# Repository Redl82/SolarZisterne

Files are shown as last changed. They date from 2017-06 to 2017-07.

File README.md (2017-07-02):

# SolarZisterne

Es handelt sich bei diesem Projekt um einen Füllstandsmesser für eine Außen-Zisterne.
Der Füllstandsmesser wir über einen ESP8266 mit dem Netzwerkverbunden und agiert als eigenständiger Web-Server.
Die Stromversorgung wird über Solarzellen gewährleistet.
Das Projekt besitz die folgenden Sensoren:
- Ultraschall Sensor für Füllstand
- Temperatur/Luftfeuchte/Luftdruck Sensor außen
- Temperatur/Luftdruck Sensor innen
- Spannung/Strom Sensor Produktion Solarzellen
- Spannung/Strom Sensor Verbrauch Elektronik

Die Lade Schaltung kann die follgenden Zustände annehmen:
            GPIO2   GPIO1   GPIO0
     Wert   STAT1   STAT2   PG      Status
     7      1       1       1       Input Power Not OK / Shutdown
     6      1       1       0       Input Power OK / No Battery Present
     4      1       0       0       Input Power OK / Charge Complete - Standby
     3      0       1       1       Input Power Not OK / Low Battery Output
     2      0       1       0       Input Power OK / Chargin Batter in Constant Current/Voltage or Preconding Mode
     0      0       0       0       Input Power OK / Temperature Fault / Temperatur Fault

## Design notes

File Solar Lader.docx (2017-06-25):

SM3320

Scheinbar nicht mehr verfügbar

SPV1040

Preiß: 4,99€

Minus:

- geht nur bis 5,5V Eingangsspannung
- Maxspannung nicht über Akkuspannung, wenn doch Akku lade IC verwenden

LT3652

Minus:

- Zieht 2,5mA aus Akku bevor geladen wird

LTM8062

BQ25504

Günstige PCBs

https://www.elecrow.com/5pcs-2-layer-pcb.html

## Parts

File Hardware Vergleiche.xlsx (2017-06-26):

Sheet: Lade ICs
 |  | ebay | aliexpress | conrad | reichelt | farnell
BQ24210 | nix
BQ25504 | 7.98 | ebay | 30 5stück |  |  | 5.99
BQ25570 | 21 | http://www.ebay.de/itm/BQ25570-thermal-solar-energy-harvester-/332071662285
LTC3105/LTC4071 |  | 3.58 | 12 5Stück | 9.13 |  | 5.27
 |  |  | 11
 |  | 11 | 34 10 Stück
LTC3106 |  |  | 17,29 2 stück |  |  | 7.05
LTC3331 |  | 11 |  |  |  | 8.73
MAX17710 |  |  |  |  |  | 15.61
ADP5090 |  | 9 |  |  |  | 5.27

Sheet: I2C Temp Sensoren
Name | Temperatur | Luftfeuchte | Druck | Temp Genauigkeit | Preis | Kommentare
BME280 | X | X | X | +/-1 | 3.75 €
MCP9808 | X |  |  | +/-0,25 | ca. 6 | günstigste nicht E-bay
MPL115A2 | X |  | X | ??? | 9.00 € | Nur ein feste Adresse
BMP280 | X |  | X | +/-1 | 1.00 €
SHT31-D | X | X |  | +/-0,3 | 5.25 €
HDC1008 | X | X |  | +/-0,2 | 3.79 € | nicht direkt
BMP085 | X | X | X | +/-2 |  | Nur ein feste Adresse, überholt

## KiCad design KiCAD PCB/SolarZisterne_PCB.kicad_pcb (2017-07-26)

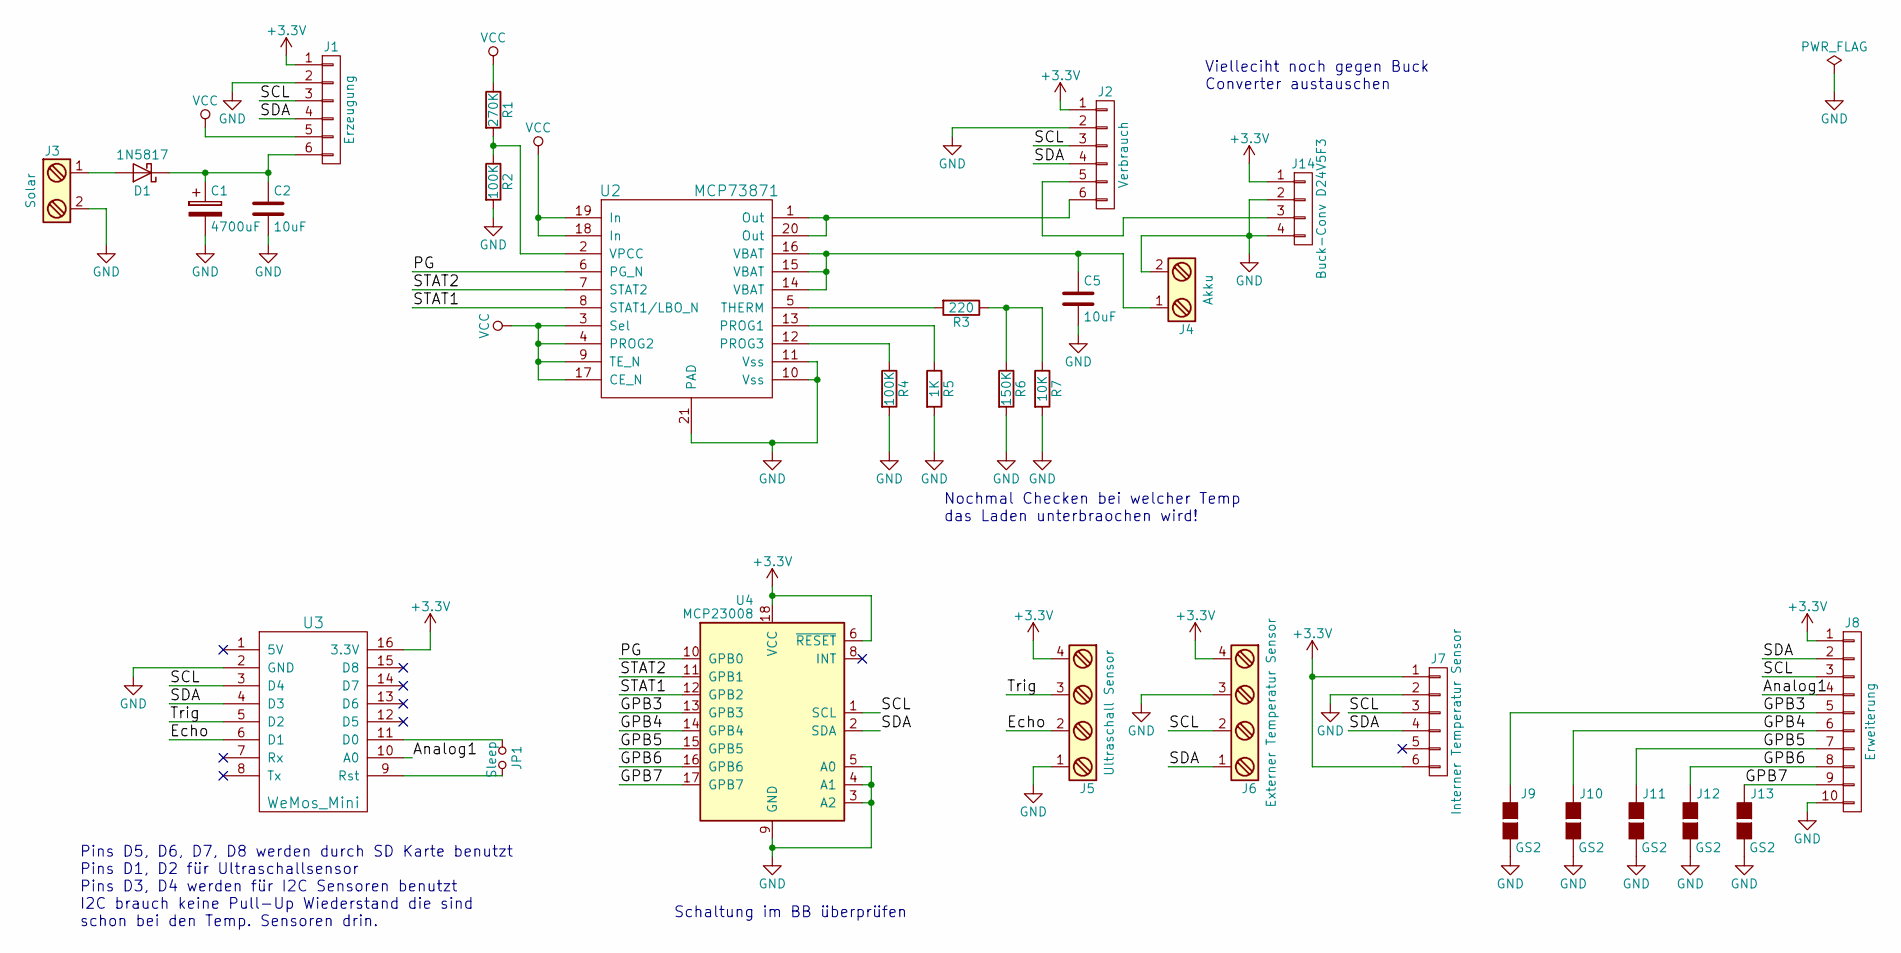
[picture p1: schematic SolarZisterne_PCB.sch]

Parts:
C1: 4700uF; CP_Radial_D16.0mm_P7.50mm
C2, C5: 10uF; C_Disc_D5.0mm_W2.5mm_P2.50mm
D1: 1N5817; D_DO-41_SOD81_P10.16mm_Horizontal
J1: Erzeugung; Pin_Header_Straight_1x06_Pitch2.54mm
J2: Verbrauch; Pin_Header_Straight_1x06_Pitch2.54mm
J3: Solar; TerminalBlock_Pheonix_PT-3.5mm_2pol
J4: Akku; TerminalBlock_Pheonix_PT-3.5mm_2pol
J5: Ultraschall Sensor; TerminalBlock_Pheonix_PT-3.5mm_4pol
J6: Externer Temperatur Sensor; TerminalBlock_Pheonix_PT-3.5mm_4pol
J7: Interner Temperatur Sensor; Pin_Header_Straight_1x06_Pitch2.54mm
J8: Erweiterung; Pin_Header_Straight_1x10_Pitch2.54mm
J9, J10, J11, J12, J13: GS2
J14: Buck-Conv D24V5F3; Pin_Header_Straight_1x04_Pitch2.54mm
JP1: Sleep; Pin_Header_Straight_1x02_Pitch2.54mm
R1: 270K; R_Axial_DIN0207_L6.3mm_D2.5mm_P10.16mm_Horizontal
R2, R4: 100K; R_Axial_DIN0207_L6.3mm_D2.5mm_P10.16mm_Horizontal
R3: 220; R_Axial_DIN0207_L6.3mm_D2.5mm_P10.16mm_Horizontal
R5: 1K; R_Axial_DIN0207_L6.3mm_D2.5mm_P10.16mm_Horizontal
R6: 150K; R_Axial_DIN0207_L6.3mm_D2.5mm_P10.16mm_Horizontal
R7: 10K; R_Axial_DIN0207_L6.3mm_D2.5mm_P10.16mm_Horizontal
U2: MCP73871; QFN-20-1EP_4x4mm_Pitch0.5mm
U3: WeMos_Mini; D1_mini_board
U4: MCP23008; DIP-18_W7.62mm_LongPads

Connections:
+3V3: J1.1, J2.1, J5.4, J6.4, J7.1, J7.6, J8.1, J14.1, U3.16 (3.3V), U4.6 (~RESET), U4.18 (VCC)
/Analog1: J8.4, U3.10 (A0)
/Echo: J5.2, U3.6 (D1)
/GPB3: J8.5, J9.1 (G1), U4.13 (GPB3)
/GPB4: J8.6, J10.1 (G1), U4.14 (GPB4)
/GPB5: J8.7, J11.1 (G1), U4.15 (GPB5)
/GPB6: J8.8, J12.1 (G1), U4.16 (GPB6)
/GPB7: J8.9, J13.1 (G1), U4.17 (GPB7)
/PG: U2.6 (PG_N), U4.10 (GPB0)
/SCL: J1.3, J2.3, J6.2, J7.3, J8.3, U3.3 (D4), U4.1 (SCL)
/SDA: J1.4, J2.4, J6.1, J7.4, J8.2, U3.4 (D3), U4.2 (SDA)
/STAT1: U2.8 (STAT1/LBO_N), U4.12 (GPB2)
/STAT2: U2.7 (STAT2), U4.11 (GPB1)
/Trig: J5.3, U3.5 (D2)
GND: C1.2, C2.2, C5.2, J1.2, J2.2, J3.2, J4.2, J5.1, J6.3, J7.2, J8.10, J9.2 (G2), J10.2 (G2), J11.2 (G2), J12.2 (G2), J13.2 (G2), J14.2, J14.4, R2.2, R4.2, R5.2, R6.2, R7.2, U2.10 (Vss), U2.11 (Vss), U2.21 (PAD), U3.2 (GND), U4.3 (A2), U4.4 (A1), U4.5 (A0), U4.9 (GND)
unnamed: C1.1, C2.1, D1.1 (K), J1.6
unnamed: C5.1, J4.1, U2.14 (VBAT), U2.15 (VBAT), U2.16 (VBAT)
unnamed: D1.2 (A), J3.1
unnamed: J2.6, U2.1 (Out), U2.20 (Out)
unnamed: J2.5, J14.3
unnamed: JP1.1, U3.11 (D0)
unnamed: JP1.2, U3.9 (Rst)
unnamed: R1.2, R2.1, U2.2 (VPCC)
unnamed: R3.1, R6.1, R7.1
unnamed: R3.2, U2.5 (THERM)
unnamed: R4.1, U2.12 (PROG3)
unnamed: R5.1, U2.13 (PROG1)
VCC: J1.5, R1.1, U2.3 (Sel), U2.4 (PROG2), U2.9 (TE_N), U2.17 (CE_N), U2.18 (In), U2.19 (In)

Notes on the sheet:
Pins D5, D6, D7, D8 werden durch SD Karte benutzt Pins D1, D2 für Ultraschallsensor Pins D3, D4 werden für I2C Sensoren benutzt I2C brauch keine Pull-Up Wiederstand die sind schon bei den Temp. Sensoren drin.
Nochmal Checken bei welcher Temp das Laden unterbraochen wird!
Schaltung im BB überprüfen
Vielleciht noch gegen Buck Converter austauschen

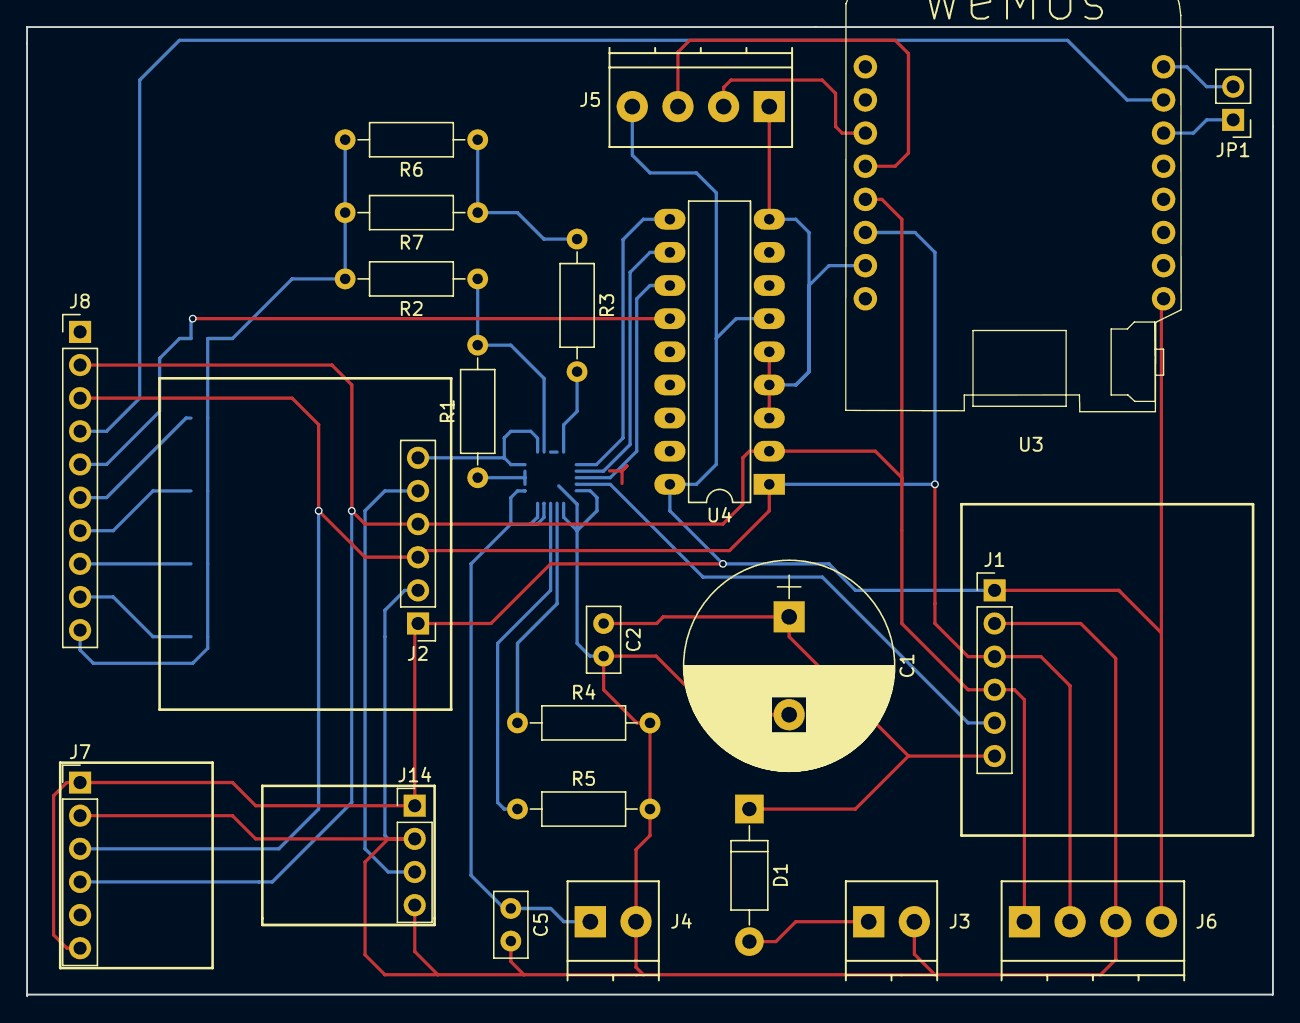
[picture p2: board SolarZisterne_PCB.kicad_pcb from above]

Board: 2 copper layers, 95.5 x 74.3 mm, 29 parts (0 on the bottom side), 28 nets.

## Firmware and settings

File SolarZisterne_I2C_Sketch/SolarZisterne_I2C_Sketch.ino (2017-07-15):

/*---------------------------------------------------
HTTP 1.1 Outdoor Webserver for WeMos Mini
for ESP8266 adapted Arduino IDE

by Daniel 07/2017 - free for anyone
---------------------------------------------------*/

#include <ESP8266WiFi.h>
#include <WiFiUdp.h>
#include <SPI.h>
#include <SD.h>
#include <Wire.h>                        // I2C
#include <Adafruit_INA219.h>             // INA219 Strommessung
#include "Adafruit_MCP23008.h"           // MCP23008
#include <Adafruit_Sensor.h>             // benötigt für Temperatur Senoren
#include <Adafruit_BME280.h>             // BME280 Temperatur Luftdruck Luftfeuchtigkeit Sensor
#include <Adafruit_BMP280.h>             // BMP280 Temperatur Luftdruck Sensor
#include "time_ntp.h"
#include "DHT.h"

// WiFi connection
const char* ssid = "Your SSID";
const char* password = "Your PW";

// ntp timestamp
unsigned long ulSecs2000_timer=0;

// storage for Measurements; keep some mem free; allocate remainder
#define KEEP_MEM_FREE 10240
#define MEAS_SPAN_H 4                   // Dauer bis Speicher, voll in Stunden 744h-->31Tage Messung ca. all 20 Min.
unsigned long ulMeasCount=0;            // values already measured
unsigned long ulNoMeasValues=0;         // size of array
unsigned long ulMeasDelta_ms;           // distance to next meas time
unsigned long ulNextMeas_ms;            // next meas time
unsigned long *pulTime;                 // array for time points of measurements
float *pfTemp,*pfHum,*pfDist;           // array for temperature, humidity and Distance measurements
float pfPres, pfTempIn, pfPresIn;        // Werte Luftdruck außen, Temperatur und Luftdruck innen
float pfSolarSp, pfSolarSt, pfSolarLe;  // Werte für Solar Spannung Strom und Leistung
float pfVerbSp, pfVerbSt, pfVerbLe;    // Werte für Verbraucher Spannung Strom und Leistung
String stStatus;                         // Array für Status 

unsigned long ulReqcount;       // how often has a valid page been requested
unsigned long ulReconncount;    // how often did we connect to WiFi

// Create an instance of the server on Port 80
WiFiServer server(80);

//////////////////////////////
// DHT21 / AMS2301 is at GPIO0
//////////////////////////////
#define DHTPIN D3

//////////////////////////////
// Ultraschall Sensor HC-SR04 Pin definition
//////////////////////////////
#define TRIGGER D4
#define ECHO    D3

// set up variables using the SD utility library functions:
Sd2Card card;
SdVolume volume;
SdFile root;

// change this to match your SD shield or module;
// WeMos Micro SD Shield: D8
const int chipSelect = D8;


//mathematische Definition des Volumens der Zisterne



// needed to avoid link error on ram check
extern "C" 
{
#include "user_interface.h"
}
// Deklariert Digitalport expander MCP23008
Adafruit_MCP23008 mcp;

// Deklariert StromMessensor INA219 
Adafruit_INA219 ina219in;                           //Sensor vor MCP73871
Adafruit_INA219 ina219out(0x41);                    //Sensor nach MCP73871

// Deklariert Temperatur Sensoren BME280 und BMP280
Adafruit_BME280 bme; // I2C
Adafruit_BMP280 bmp; // I2C

/////////////////////
// the setup routine
/////////////////////
void setup() 
{
  // setup globals
  ulReqcount=0; 
  ulReconncount=0;
    
  // start serial
  Serial.begin(9600);
  Serial.println();
  Serial.println("########################################################################################################");
  Serial.println("#Zisternen Wasserstandsanzeige, Temperatur und Feuchtigkeitslogger - D. Redlich 04/2017                #");
  Serial.println("#Basis des Programms kann unter:                                                                       #");
  Serial.println("#https://blog.thesen.eu/wlan-lufttemperatur-und-feuchte-logger-mit-grafischer-darstellung-fuer-esp8266/#");
  Serial.println("#gefunden werden.                                                                                      #");
  Serial.println("########################################################################################################");
  Serial.println();
  
  //Start I2C
  Wire.begin();
  Serial.println("########################################################################################################");
  Serial.println("");
  Serial.println("I2C initialisiert!");
  Serial.println("SCL auf Pin D1 und SCA auf Pin D2");
  //Sucht nach benutzten GPIO Adressen
  byte error, address;
  int nDevices;

  Serial.println("Suche nach Geräten...");
  
  nDevices = 0;
  for(address = 1; address < 127; address++ ) 
  {
    // The i2c_scanner uses the return value of
    // the Write.endTransmisstion to see if
    // a device did acknowledge to the address.
    Wire.beginTransmission(address);
    error = Wire.endTransmission();

    if (error == 0)
    {
      Serial.print("I2C Gerät auf adresse 0x");
      if (address<16) 
        Serial.print("0");
      Serial.print(address,HEX);
      Serial.println("  gefunden !");

      nDevices++;
    }
    else if (error==4) 
    {
      Serial.print("Unknown error at address 0x");
      if (address<16) 
        Serial.print("0");
      Serial.println(address,HEX);
    }    
  }
  if (nDevices == 0)
    Serial.println("No I2C devices found\n");
  else
    Serial.println("Fertsch\n");

  mcp.begin();                // use default address 0x20 oder 0 GPIO Expander 
  
  Serial.println("GPIO Erweiterung auf 0x20 eingerichtet!");
  
  mcp.pinMode(0, INPUT);      // definiert Pin 0 als Input --> PG
  mcp.pinMode(1, INPUT);      // definiert Pin 1 als Input --> STAT2
  mcp.pinMode(2, INPUT);      // definiert Pin 2 als Input --> STAT1
  mcp.pullUp(0, HIGH);        // turn on a 100K pullup internally
  mcp.pullUp(1, HIGH);        // turn on a 100K pullup internally
  mcp.pullUp(2, HIGH);        // turn on a 100K pullup internally

  Serial.println("GPIO0 --> PG");
  Serial.println("GPIO1 --> STAT1");
  Serial.println("GPIO2 --> STAT2");

  Serial.println("Pull-Up Wiederstände wurden eingeschaltet");
  
  Serial.println("");
  Serial.println("########################################################################################################");
  Serial.println("");

  //Einrichten der Stromsensoren
  Serial.println("########################################################################################################");
  Serial.println("");
  ina219in.begin();
  ina219out.begin();
  Serial.println("Sensor zum messen des Solar Eingans Stromes und Spannung wurden auf der Adresse 0X40 eingerichtet");
  Serial.println("Sensor zum messen des Verbrauchten Stromes und Spannung wurden auf der Adresse 0X41 eingerichtet");
  Serial.println("");
  Serial.println("########################################################################################################");
  Serial.println("");

  //Einrichten der Temperatur Sensoren
  Serial.println("########################################################################################################");
  Serial.println("");
  bme.begin();
  bmp.begin();
  if (!bmp.begin()) 
  {  
    Serial.println("BMP280 Sensor konnt auf auf 0X77 gefunden werden");
  }
  else
  {
  Serial.println("Sensor zum messen des internen Temperatur(BMP280) wurden auf der Adresse 0X77 eingerichtet"); 
  }
  if (!bme.begin(0x76)) 
  {  
    Serial.println("BME280 Sensor konnt auf auf 0X76 gefunden werden");
  }
  else
  {
  Serial.println("Sensor zum messen des externen Temperatur (BME280) wurden auf der Adresse 0X76 eingerichtet"); 
  }
  Serial.println("");
  Serial.println("########################################################################################################");
  Serial.println("");
  
  //Definition der Pins für Ultraschall Sensor
  pinMode(TRIGGER, OUTPUT);
  pinMode(ECHO, INPUT);
  Serial.println("########################################################################################################");
  Serial.println("");
  Serial.println("Ultraschall Sensor wurde wie folgt eingerichte:");
  Serial.println("Ultraschall Sensor wird eingerichte:");
  Serial.print("Triger auf Pin ");
  Serial.println(TRIGGER);
  Serial.print("Echo auf Pin ");
  Serial.println(ECHO);
  Serial.println("");
  Serial.println("Ultraschall Sensor wurde wie folgt eingerichte:");
  Serial.println("");
  Serial.println("########################################################################################################");
  
  // inital connect
  WiFi.mode(WIFI_STA);
  WiFi.hostname("Zisterne");
  WiFiStart();

  //Einrichten der SD-Karte

  Serial.println("");
  Serial.println("########################################################################################################");
  Serial.println("");
  Serial.println("Initializing SD card...");
  if (!card.init(SPI_HALF_SPEED, chipSelect)) 
  {
    Serial.println("Es wurde keine SD-Karte gefunden! Es können keine Messdaten gespeichert werden extern gespeichert werden!");
    //Serial.println("* is a card inserted?");
    //Serial.println("* is your wiring correct?");
    //Serial.println("* did you change the chipSelect pin to match your shield or module?");
    //return;
  } 
  else 
  {
    Serial.println("SD-Karte wurde gefunden. Karte wird eigerichtet, damit Messdaten darauf gespeichert werden können!");

      // print the type of card
      Serial.print("Card type: ");
      switch (card.type()) {
        case SD_CARD_TYPE_SD1:
          Serial.println("SD1");
          break;
        case SD_CARD_TYPE_SD2:
          Serial.println("SD2");
          break;
        case SD_CARD_TYPE_SDHC:
          Serial.println("SDHC");
          break;
        default:
          Serial.println("Unknown");
      }
      // Now we will try to open the 'volume'/'partition' - it should be FAT16 or FAT32
      if (!volume.init(card)) {
        Serial.println("Could not find FAT16/FAT32 partition.\nMake sure you've formatted the card");
        return;
      }
        // print the type and size of the first FAT-type volume
      uint32_t volumesize;
      Serial.print("Volume type is FAT");
      Serial.println(volume.fatType(), DEC);
      volumesize = volume.blocksPerCluster();       // clusters are collections of blocks
      volumesize *= volume.clusterCount();          // we'll have a lot of clusters
      volumesize *= 512;                            // SD card blocks are always 512 bytes
      Serial.print("Volume size (bytes): ");
      Serial.print(volumesize);
      Serial.println("  (Muss nicht stimmen)");
      // see if the card is present and can be initialized:
      if (!SD.begin(chipSelect)) 
      {
        Serial.println("Card failed, or not present");
        // don't do anything more:
      }
      Serial.println("Einrichten der SD-Karte abgeschlossen");
  
    }

  Serial.println("");
  Serial.println("########################################################################################################");
  Serial.println("");

  // allocate ram for data storage
  uint32_t free=system_get_free_heap_size() - KEEP_MEM_FREE;
  ulNoMeasValues = free / (sizeof(float)*3+sizeof(unsigned long));  // humidity & temp --> 2 + time
  pulTime = new unsigned long[ulNoMeasValues];
  pfTemp = new float[ulNoMeasValues];
  pfHum = new float[ulNoMeasValues];
  pfDist = new float[ulNoMeasValues];
  
  if (pulTime==NULL || pfTemp==NULL || pfHum==NULL || pfDist==NULL)
  {
    ulNoMeasValues=0;
    Serial.println("Error in memory allocation!");
  }
  else
  {
    Serial.print("Allocated storage for ");
    Serial.print(ulNoMeasValues);
    Serial.println(" data points.");
    
    float fMeasDelta_sec = MEAS_SPAN_H*3600./ulNoMeasValues;
    ulMeasDelta_ms = ( (unsigned long)(fMeasDelta_sec+0.5) ) * 1000;  // round to full sec
    Serial.print("Measurements will happen each ");
    Serial.print(ulMeasDelta_ms);
    Serial.println(" ms.");
    
    ulNextMeas_ms = millis()+ulMeasDelta_ms;

    Serial.println("");
    Serial.println("########################################################################################################");
    Serial.println("");
  }
delay(100); // let sensors boot up 
}


///////////////////
// (re-)start WiFi
///////////////////
void WiFiStart()
{
  ulReconncount++;
  
  // Connect to WiFi network
  Serial.println();

  Serial.print("Connecting to ");
  Serial.println(ssid);
  
  WiFi.begin(ssid, password);
  
  while (WiFi.status() != WL_CONNECTED) 
  {
    delay(500);
    Serial.print(".");
  }
  Serial.println("");
  Serial.println("WiFi connected");
  
  // Start the server
  server.begin();
  Serial.println("Server started");

  // Print the IP address
  Serial.println("");
  Serial.println("#############################################################################################");
  Serial.print("# Die Messwert sind im Browser unter 'Zisterne' oder unter der IP:");
  Serial.print(WiFi.localIP());
  Serial.println(" erreichbar! #");
  Serial.println("#############################################################################################");
  Serial.println("");
    
  ///////////////////////////////
  // connect to NTP and get time
  ///////////////////////////////
  Serial.println("Aktuelle Uhrzeit wird ermittel...");
  ulSecs2000_timer=getNTPTimestamp();
  Serial.print("Current Time UTC from NTP server: " );
  Serial.println(epoch_to_string(ulSecs2000_timer).c_str());

  ulSecs2000_timer -= millis()/1000;  // keep distance to millis() counter
}


/////////////////////////////////////
// make html table for measured data
/////////////////////////////////////
unsigned long MakeTable (WiFiClient *pclient, bool bStream)
{
  unsigned long ulLength=0;
  
  // here we build a big table.
  // we cannot store this in a string as this will blow the memory   
  // thus we count first to get the number of bytes and later on 
  // we stream this out
  if (ulMeasCount==0) 
  {
    String sTable = "Noch keine Daten verf&uuml;gbar.<BR>";
    if (bStream)
    {
      pclient->print(sTable);
    }
    ulLength+=sTable.length();
  }
  else
  { 
    unsigned long ulEnd;
    if (ulMeasCount>ulNoMeasValues)
    {
      ulEnd=ulMeasCount-ulNoMeasValues;
    }
    else
    {
      ulEnd=0;
    }
    
    String sTable;
    sTable = "<table style=\"width:100%\"><tr><th>Zeit / UTC</th><th>T &deg;C</th><th>Hum &#037;</th><th>F&uuml;llstand &#037;</th></tr>";
    sTable += "<style>table, th, td {border: 2px solid black; border-collapse: collapse;} th, td {padding: 5px;} th {text-align: left;}</style>";
    for (unsigned long li=ulMeasCount;li>ulEnd;li--)
    {
      unsigned long ulIndex=(li-1)%ulNoMeasValues;
      sTable += "<tr><td>";
      sTable += epoch_to_string(pulTime[ulIndex]).c_str();
      sTable += "</td><td>";
      sTable += pfTemp[ulIndex];
      sTable += "</td><td>";
      sTable += pfHum[ulIndex];
      sTable += "</td><td>";
      sTable += pfDist[ulIndex];
      sTable += "</td></tr>";

      // play out in chunks of 1k
      if(sTable.length()>1024)
      {
        if(bStream)
        {
          pclient->print(sTable);
          //pclient->write(sTable.c_str(),sTable.length());
        }
        ulLength+=sTable.length();
        sTable="";
      }
    }
    
    // remaining chunk
    sTable+="</table>";
    ulLength+=sTable.length();
    if(bStream)
    {
      pclient->print(sTable);
      //pclient->write(sTable.c_str(),sTable.length());
    }   
  }
  
  return(ulLength);
}
  

////////////////////////////////////////////////////
// make google chart object table for measured data
////////////////////////////////////////////////////
unsigned long MakeList (WiFiClient *pclient, bool bStream)
{
  unsigned long ulLength=0;
  
  // here we build a big list.
  // we cannot store this in a string as this will blow the memory   
  // thus we count first to get the number of bytes and later on 
  // we stream this out
  if (ulMeasCount>0) 
  { 
    unsigned long ulBegin;
    if (ulMeasCount>ulNoMeasValues)
    {
      ulBegin=ulMeasCount-ulNoMeasValues;
    }
    else
    {
      ulBegin=0;
    }
    
    String sTable="";
    for (unsigned long li=ulBegin;li<ulMeasCount;li++)
    {
      // result shall be ['18:24:08 - 21.5.2015',21.10,49.00],
      unsigned long ulIndex=li%ulNoMeasValues;
      sTable += "['";
      sTable += epoch_to_string(pulTime[ulIndex]).c_str();
      sTable += "',";
      sTable += pfTemp[ulIndex];
      sTable += ",";
      sTable += pfHum[ulIndex];
      sTable += ",";
      sTable += pfDist[ulIndex];
      sTable += "],\n";

      // play out in chunks of 1k
      if(sTable.length()>1024)
      {
        if(bStream)
        {
          pclient->print(sTable);
          //pclient->write(sTable.c_str(),sTable.length());
        }
        ulLength+=sTable.length();
        sTable="";
      }
    }
    
    // remaining chunk
    if(bStream)
    {
      pclient->print(sTable);
      //pclient->write(sTable.c_str(),sTable.length());
    } 
    ulLength+=sTable.length();  
  }
  
  return(ulLength);
}
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
void loop() 
{
  ///////////////////
  // do data logging
  ///////////////////
  if (millis()>=ulNextMeas_ms) 
  {
    ulNextMeas_ms = millis()+ulMeasDelta_ms;
    
    //Messung des Zisternen Füllstandes
    digitalWrite(TRIGGER, LOW);  
    delayMicroseconds(2); 
  
    digitalWrite(TRIGGER, HIGH);
    delayMicroseconds(10); 
  
    digitalWrite(TRIGGER, LOW);
    
    pfDist[ulMeasCount%ulNoMeasValues]=((pulseIn(ECHO, HIGH)/2) / 29.1);   //Misst die Zeit von bis zur die Signal brauch vom Aussendenbis zur Rückkehr
                                                                                               // /2 /29,1 rechnet Zeit in Distanz in mm um

    
    //pfDist[ulMeasCount%ulNoMeasValues]= map(((pulseIn(ECHO, HIGH)/2) / 29.1),0,200,0,100);   //Misst die Zeit von bis zur die Signal brauch vom Aussendenbis zur Rückkehr
                                                                                               // /2 /29,1 rechnet Zeit in Distanz in mm um
                                                                                               // Map Befehl errechnet daraus eine Prozent Zhal des Füll Standes    
    //Messung der externen Luftfeuchtigkeit, Temperatur und des Luftdruck
    pfHum[ulMeasCount%ulNoMeasValues] = bme.readHumidity();
    pfTemp[ulMeasCount%ulNoMeasValues] = bme.readTemperature();
    pulTime[ulMeasCount%ulNoMeasValues] = millis()/1000+ulSecs2000_timer;
    pfPres=bme.readPressure()/100;

    //Messung der internen Temperatur und des Luftdruck
    pfTempIn=bmp.readTemperature();
    pfPresIn=bmp.readPressure()/100; 

    //Status der Solar-Lade Schaltung

    /*
            GPIO2   GPIO1   GPIO0
     Wert   STAT1   STAT2   PG      Status
     7      1       1       1       Input Power Not OK / Shutdown
     6      1       1       0       Input Power OK / No Battery Present
     4      1       0       0       Input Power OK / Charge Complete - Standby
     3      0       1       1       Input Power Not OK / Low Battery Output
     2      0       1       0       Input Power OK / Chargin Batter in Constant Current/Voltage or Preconding Mode
     0      0       0       0       Input Power OK / Temperature Fault / Temperatur Fault
    */
    
    switch (mcp.readGPIO()) 
    {
      case 0:
        stStatus="Input Power OK / Temperatur Fehler oder Timer Fehler (0)";
        break;
      case 1:
        stStatus="Nicht definert";
        break;
      case 2:
        stStatus="Input Power OK / Chargin Batter in Constant Current/Voltage or Preconding Mode (2)";
        break;
      case 3:
        stStatus="Input Power Not OK / Low Battery Output (3)";
        break;
      case 4:
        stStatus="Input Power OK / Charge Complete - Standby (4)";
        break;
      case 5:
        stStatus="Nicht definert";
        break;
      case 6:
        stStatus="Input Power OK / No Battery Present (6)";
        break;
      case 7:
        stStatus="Input Power Not OK / Shutdown (7)";
        break;
    }  
    //Messung von Spannung und Strom der Solar-Schaltung
    // Solarzellen --> MCP73871
    pfSolarSp = ina219in.getBusVoltage_V();
    pfSolarSt = ina219in.getCurrent_mA();
    pfSolarLe = pfSolarSt/1000*pfSolarSp; 
    // MCP73871 --> Spannungsregler WEMOS
    pfVerbSp = ina219out.getBusVoltage_V();
    pfVerbSt = ina219out.getCurrent_mA();
    pfVerbLe = pfVerbSt/1000*pfVerbSp;            
    

    //Seriele Ausgabe des Status
    Serial.print("Logging External Temperature: "); 
    Serial.print(pfTemp[ulMeasCount%ulNoMeasValues]);
    Serial.print(" deg C - Humidity: "); 
    Serial.print(pfHum[ulMeasCount%ulNoMeasValues]);
    Serial.print("% - Pressure: ");
    Serial.print(pfPres);
    Serial.print("hPa - Filled: ");
    Serial.print(pfDist[ulMeasCount%ulNoMeasValues]);
    Serial.print("% - Time: ");
    Serial.println(pulTime[ulMeasCount%ulNoMeasValues]);
    Serial.print("Logging Internal Temperature: ");
    Serial.print(pfTempIn);
    Serial.print(" deg C - Pressure: ");
    Serial.print(pfPresIn);
    Serial.println("hPa ");
    Serial.print("Energie Status: ");
    Serial.println(stStatus);
    Serial.print("Logging Solar Spannung: ");
    Serial.print(pfSolarSp);
    Serial.print(" V - Strom: ");
    Serial.print(pfSolarSt);
    Serial.print(" mA - Leistung: ");
    Serial.print(pfSolarLe);
    Serial.println(" W");
    Serial.print("Logging Verbrauch Spannung: ");
    Serial.print(pfVerbSp);
    Serial.print(" V - Strom: ");
    Serial.print(pfVerbSt);
    Serial.print(" mA - Leistung: ");
    Serial.print(pfVerbLe);
    Serial.println(" W");
    Serial.println("#############################################################################################");
    
  //////////////////////////////
  //Messwerte auf SD-Karte speichern
  //////////////////////////////
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

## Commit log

2017-06-25 Initial Version
    [SolarZisterne_PCB.kicad_pcb, SolarZisterne_PCB.sch]
2017-06-25 DHT Sensoren funktionieren
2017-06-25 ACS712 strommessung implementiert
    Sehr ungenau bei 0A Messung zeigt an das 50-100 mA fließen
2017-06-26 Konzept auf I2C
    Alle Temp und Strom Senoren werden über I2C angesteuert Digitale I/O werden auch über I2C erweiter. Kein AT MEGA mehr.
    [Hardware Vergleiche.xlsx, SolarZisterne_PCB.sch]
2017-06-28 Erster Entwurf des kompletten Schaltplans
    [SolarZisterne_PCB.sch]
2017-06-30 Thermal Sensoren eingefügt
    [SolarZisterne_PCB.sch]
2017-07-02 PCB angefangen
    [SolarZisterne_PCB.sch]
2017-07-02 weiter gearbeite
    [SolarZisterne_PCB.kicad_pcb, SolarZisterne_PCB.sch]
2017-07-02 Aufgeräumt und am Programm gearbeitet
    [SolarZisterne_PCB.kicad_pcb, SolarZisterne_PCB.sch]
2017-07-09 Sicherung bevor die Messung mit den DHT22 Sensoren entfernt wird
    [SolarZisterne_PCB.kicad_pcb, SolarZisterne_PCB.sch]
2017-07-15 Before Änderung Ultraschall
    [SolarZisterne_PCB.sch]
2017-07-23 PCB Update
    [SolarZisterne_PCB.kicad_pcb, SolarZisterne_PCB.sch]
2017-07-26 fast aller Leiterbahnen
    [SolarZisterne_PCB.kicad_pcb, SolarZisterne_PCB.sch]
